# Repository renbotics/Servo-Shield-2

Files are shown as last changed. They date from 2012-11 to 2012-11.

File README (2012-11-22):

The Renbotics Servo Shield Rev 2 is an Arduino-compatible shield that uses only two pins to drive 16 servos per shield. The Renbotics Servo Shield Rev 2 uses a PCA9685 over I2C to provide 16 free-running servo outputs. The address of the board is selectable via a DIP switch making it easy to stack up to 62 shields to control up to 992 servos. Two jumpers make it easy to select the Arduino host model used.

www.renbotics.com.au

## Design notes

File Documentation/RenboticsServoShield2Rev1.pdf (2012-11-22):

Renbotics | Servo Shield 2
Applications • | Robotics
- Animatronics
- Mechatronic Art

Features • 16 Servo Channels

- Convenient screw terminal for servo power supply
- 196 Point breadboard style prototyping area
- Compatible with Arduino
Duemilanove, UNO, Leonardo and Arduino Mega 2560
- Dip switch to easily set and/or change address
- 50Hz or 60Hz mode
- Easy to use API

www.renbotics.com | Renbotics Servo Shield Rev 2 Support:support@renbotics.com

## 1. License

Renbotics Servo Shield Rev 2 by Renbotics is licensed under a Creative Commons Attribution 2.5 Australia License.

## 2. Disclaimer of Liability

Renbotics is not responsible for any special, incidental, or consequential damages resulting from any breach of warranty, or under any legal theory, including lost profits, downtime, good-will, damage to or replacement of equipment or property, and any costs or recovering of any material or goods associated with the assembly or use of this product. Renbotics reserves the right to make substitutions and changes to this product without prior notice.

## 3. Description

The Renbotics Servo Shield Rev 2 is an Arduino-compatible shield that uses only two pins to drive 16 servos per shield. The Renbotics Servo Shield Rev 2 uses a PCA9685 over I2C to provide 16 free-running servo outputs. The address of the board is selectable via a DIP switch making it easy to stack up to 62 shields to control up to 992 servos. Two jumpers make it easy to select the Arduino host model used.

## 4. Overview

Image 1: Renbotics Servo Shield Rev 2 Overview

## 5. Features

- 16 Servo Channels
- Convenient screw terminal for servo power supply
- 196 Point breadboard style prototyping area
- Compatible with Arduino Duemilanove, UNO, Leonardo and Arduino Mega 2560
- Dip switch to easily set and/or change address
- 50Hz or 60Hz mode
- Easy to use API

## 6. Applications

- Robotics
- Animatronics
- Mechatronic Art

## 7. Parts List

Image 2:Renbotics Servo Shield Rev 2 Parts

1 x Renbotics Servo Shield Rev 2 PCB with all surface mount components 1 x 10 pin Female Stacking Header
2 x 8 pin Female Stacking Headers
2 x 6 pin Female Stacking Headers
1 x 2 pin Screw Terminal
6 x 8 pin Male Breakaway Headers 2 x 3 pin Male Breakaway Headers 2 x Jumpers

## 8. Assembly

## 9. RC Servo Control Basics

A RC Servo is controlled by sending it a pulses ranging from 1ms to 2ms in duration, Pulse-width modulation (PWM), at 50Hz (50 pulses per second) or more. On a typical servo a 1.5ms pulse will center a servo at 90deg, a 1ms pulse will move the servo to 0deg and a 2ms pulse will move the servo to 180deg (See Image 8).

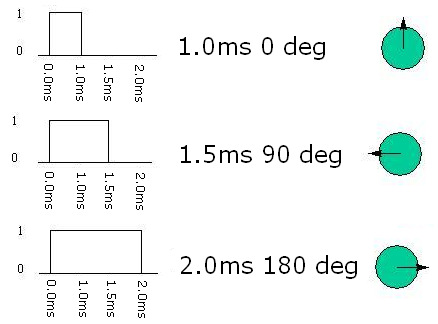
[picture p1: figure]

Image 8: Servo Control Overview | Image 9: Servo Cable

A typical RC Servo has three wires, one for the control signal and the other two for power (See Image 9).

The most common wire colors are:
Signal | White or Orange
Negative | Black
Positive | Red or Brown

On the Servo Shield the Negative (Black) wire always faces to the outside of the board.

Image 10: Renbotics Servo Shield Rev 2 power wiring

## 10. Library

## Installing

## the

## Library

Download servoshield.zip from http://www.renbotics.com/files/servoshield2.zip and extract it to your arduino-[version]/hardware/libraries folder.

## Functions

ServoShield2 ServoShield2(uint8_t addr, uint8_t mode)

Initializes the Servo Shield 2 at the address specified using the mode specified. Two modes are supported 50Hz and 60Hz. The mode determines the rate at which the servo’s positions are updated. The default mode is 50Hz.

e.g.
ServoShield2 servos = ServoShield2(127, 50);

int setposition(int servo, int position);

Sets the position of the specified servo. Returns 0 if successfully set; returns 1 if instruction failed.

e.g.
servos.setposition(1, 1500);

int setbounds(int servo, int minposition, int maxposition);

Sets the valid maximum and minimum bounds of the specified servo; returns 1 if instruction failed.

Defaults are 1000 and 2000.

e.g.
servos.setbounds(1, 1000, 2000);

int getposition(int Servo);

Returns the current position of the specified servo.

e.g.
int position = servos.getposition(1);

int start();

Starts the servo controller.

e.g.
servos.start();

int invertservo(int servo);

Inverts the signal sent to the servo, e.g. if invert is set and a position of 1000 is sent to the servo it will automatically be inverted to 2000.

e.g.
servos.invertservo(1);

## 11. Selecting Arduino Model

Different Arduino’s and Arduino Compatible boards have their I2C pins, SCL and SDA, located in diffident places.

If you are using a new Arduino, e.g. the Leonardo, or an Arduino Mega the I2C pins are located to the left of digital pin 13. For these boards place the jumpers over position A.

Image 11: Renbotics Servo Shield Rev 2 Jumpers in position A

For older Arduino’s, e.g. the Duemilanove, the I2C pins are the same as analogue pins 4 and 5. For these boards place the jumpers over position B.

Image 12: Renbotics Servo Shield Rev 2 Jumpers in position B

## 12. Addressing

127 | 126 | 125 | 124 | 123 | 122 | 121 | 120
119 | 118 | 117 | 116 | 115 | 114 | 113 | 112
111 | 110 | 109 | 108 | 107 | 106 | 105 | 104
103 | 102 | 101 | 100 | 99 | 98 | 97 | 96
95 | 94 | 93 | 92 | 91 | 90 | 89 | 88
87 | 86 | 85 | 84 | 83 | 82 | 81 | 80
79 | 78 | 77 | 76 | 75 | 74 | 73 | 72
71 | 70 | 69 | 68 | 67 | 66 | 65 | 64
Image 13: Renbotics Servo Shield Rev 2 address table

## Appendix A Sample Sketches

Sample 1: Simple servo sweeper

#include <Wire.h>

#include <ServoShield2.h>

ServoShield2 servos = ServoShield2(127);//Address of 127, using 50Hz mode

void setup() {
Serial.begin(9600);
Serial.println("Initializing...");
servos.start();

for (int servo = 0; servo < 16; servo++)//Initialize all 16 servos
{
servos.setbounds(servo, 1000, 2000); //Set the minimum and maximum pulse duration
servos.setposition(servo, 1500); | //Set the initial position of the servo
}
Serial.println("Init Done");
}

void sweep()
{
Serial.println("Sweeping");

for(int pos = 1000; pos < 2000; pos += 20) //Move the servos from 0 degrees to 180 {
for (int i = 0; i < 16; i++)
servos.setposition(i, pos);
delay(1);
}

for(int pos = 2000; pos >= 1000; pos -= 20) //Move the servos from 180 degrees to 0 {
for (int i = 0; i < 16; i++)
servos.setposition(i, pos);
delay(1);
}
}

void loop() {
sweep();
}

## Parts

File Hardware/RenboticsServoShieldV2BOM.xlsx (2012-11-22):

Electronic Engineering BOM List
Product Name： Renbotics Servo Shield
Version：V2.0
Issue Date：27/08/2012
Item No. (序号) | Reference Des (上件位置) | Qty (用量) | Catalog (分类） | Part_Description (规格描述) | Part_Value （元件值） | Part_Package （元件封装） | Manufacturers Name (使用厂牌名称) | Manufacturers Part No. (使用厂牌型号) | Distributors Name （供应商名称） | Distributors Part No. (供貨商型号) | Unit Price （单价） | Price Break To Use （价格分段的购买量） | Notes/Remark （备注）
1 | R1 | 1 | Resister | RES 4.7K OHM | 4K7 | C0805 | Vishay Dale | CRCW08054K70JNEA | Digikey | 541-4.7KATR-ND | 0.00544 |  | Ok to substitute for equivalent
2 | R2 | 1 | Resister | RES 4.7K OHM | 4K7 | C0805 | Vishay Dale | CRCW08054K70JNEA | Digikey | 541-4.7KATR-ND | 0.00544 |  | Ok to substitute for equivalent
3 | R3 | 1 | Resister | RES 10K OHM | 10K | C0805 | Vishay Dale | CRCW080510K0JNEA | Digikey | 541-10KACT-ND |  |  | Ok to substitute for equivalent
4 | R4 | 1 | Resister | RES 10K OHM | 10K | C0805 | Vishay Dale | CRCW080510K0JNEA | Digikey | 541-10KACT-ND |  |  | Ok to substitute for equivalent
5 | R5 | 1 | Resister | RES 10K OHM | 10K | C0805 | Vishay Dale | CRCW080510K0JNEA | Digikey | 541-10KACT-ND |  |  | Ok to substitute for equivalent
6 | R6 | 1 | Resister | RES 10K OHM | 10K | C0805 | Vishay Dale | CRCW080510K0JNEA | Digikey | 541-10KACT-ND |  |  | Ok to substitute for equivalent
7 | R7 | 1 | Resister | RES 10K OHM | 10K | C0805 | Vishay Dale | CRCW080510K0JNEA | Digikey | 541-10KACT-ND |  |  | Ok to substitute for equivalent
8 | R8 | 1 | Resister | RES 10K OHM | 10K | C0805 | Vishay Dale | CRCW080510K0JNEA | Digikey | 541-10KACT-ND |  |  | Ok to substitute for equivalent
9 | C1 | 1 | Capacitor | CAP CER 10000PF 50V 10% | 10nf | C0805 | Kemet | C0805C103K5RACTU | Digikey | 399-1158-2-ND |  |  | Ok to substitute for equivalent
10 | U1 | 1 | IC | IC LED DVR PWN 16CH | PCA9685 | TSSOP28 | NXP | PCA9685PW | Digikey | 568-5305-6-ND |  |  | Ok to substitute for equivalent
11 | S1 | 1 | OTHER | SWITCH DIP 6POS TOP ACT GULLEAD |  |  | Omron | A6S-6104-H | Digikey | SW1015-ND |  |  | Ok to substitute for equivalent
12 | X1 | 1 | OTHER | TERM BLOCK 2POS SIDE ENTRY 5mm |  |  | Buchanan | 1776244-2 | Digikey | A97996-ND |  |  | Ok to substitute for equivalent
13 |  | 2 | OTHER | CONN HEADER 36POS .100 VERT TIN |  |  | Molex | 0022284360 | Digikey | WM6436-ND |  |  | Ok to substitute with any combination that allows the customer to get 6 x 8pin and 2 x 3pin headers
14 |  | 2 | OTHER | SHUNT JUMPER .1" BLACK |  |  | 3M | 969102-0000-DA | Digikey | 3M9580-ND |  |  | Ok to substitute for equivalent
15 |  | 2 | OTHER | Stackable Header 6 pin |  |  | 4UCON | 18688 | 4UCON | 18688 |  |  | Ok to substitute for equivalent
16 |  | 2 | OTHER | Stackable Header 8 pin |  |  | 4UCON | 18689 | 4UCON | 18689 |  |  | Ok to substitute for equivalent
17 |  | 1 | OTHER | Stackable Header 10 pin |  |  | 4UCON | 19950 | 4UCON | 19950 |  |  | Ok to substitute for equivalent
18 |  | 1 | OTHER | Renbotics Servo Shield Rev 2 PCB |  |  | SeeedStudio |  | SeeedStudio |  |  |  | All surfacemount components to be soldered by SeeedStudio
1. Recommended Distributor: Digi-Key, Mouser, Avnet Express, Farnell.
2. Catalog: Capacitor,Resister,Diode,Connector,Transistor,IC,PROTECTOR CATEGORY,OTHER
3. Required Fields: Item No, Reference Des, Qty, Catalog, Part_Value, Part Package
Optional Fields: Part_Description, Manufacturers Name, Manufacturers Part No, Distributors Name, Distributors Part No, Unit Cost, Price break to use, Notes/Remark

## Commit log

2012-12-02 Updated invert servo handling
2012-12-19 Fritzing component for the Servo Shield 2
